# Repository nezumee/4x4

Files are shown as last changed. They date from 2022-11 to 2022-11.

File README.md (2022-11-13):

# 4x4 keyboard
 
The 4x4 keyboard is a modular keyboard with per-key RGB lighting intended to be used as a base for prototyping MIDI controller with QMK firmware.

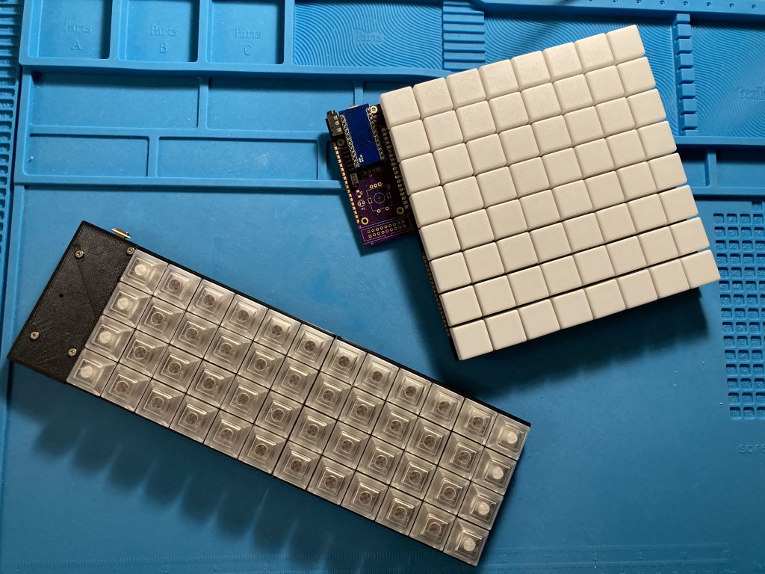
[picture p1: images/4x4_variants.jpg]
4x4 variants


It consists of the following parts:
* Head PCB with MCU and other connectors
* 1 to 4 key PCB, each having 16 hotswap Cherry MX switches in 4x4 layout

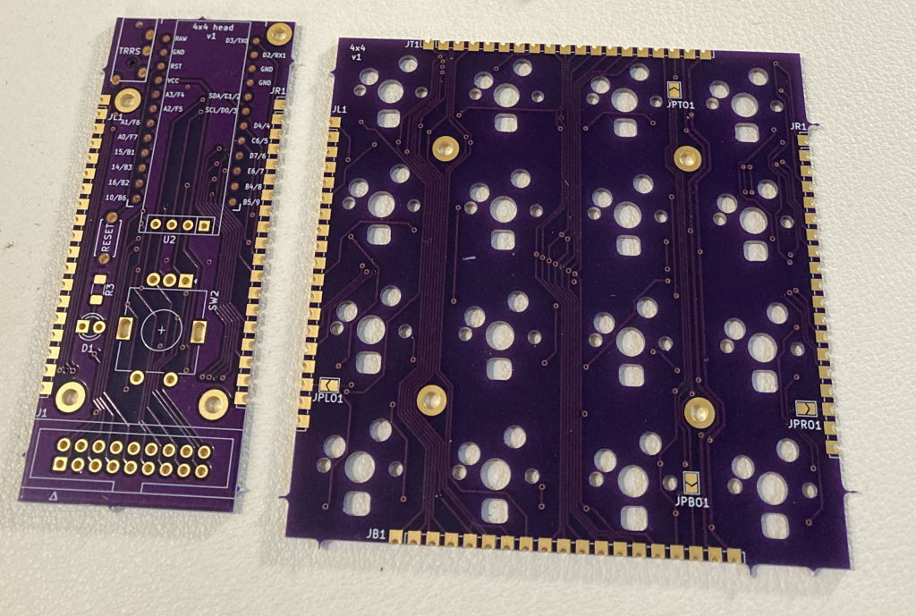
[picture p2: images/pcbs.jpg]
PCB parts


These parts can be soldered together in different configurations, resulting in different layouts, such as 4x12 Planck layout or 8x8 layout similar to MIDI drumpads controllers.

The modular design allows to iterate on parts of it without remaking a large PCB. It also makes it cost-effective to order from PCB prototyping service - ordering the typical minimum of 3 to 5 pieces of key PCB makes a single full-sized keyboard with no excessive number of spares.

PCB pieces use castellated pads to route all the signals. These pads are soldered together placing the PCBs side by side, connecting them electrically and also holding them together physically.

## Switch matrix

To allow for modularity and avoid using lots of wires to connect parts together, electrical layout of the key PCBs doesn't match their physical layout. Even though physically they are 4x4, electrically switches are laid out in 2 columns and 8 rows:
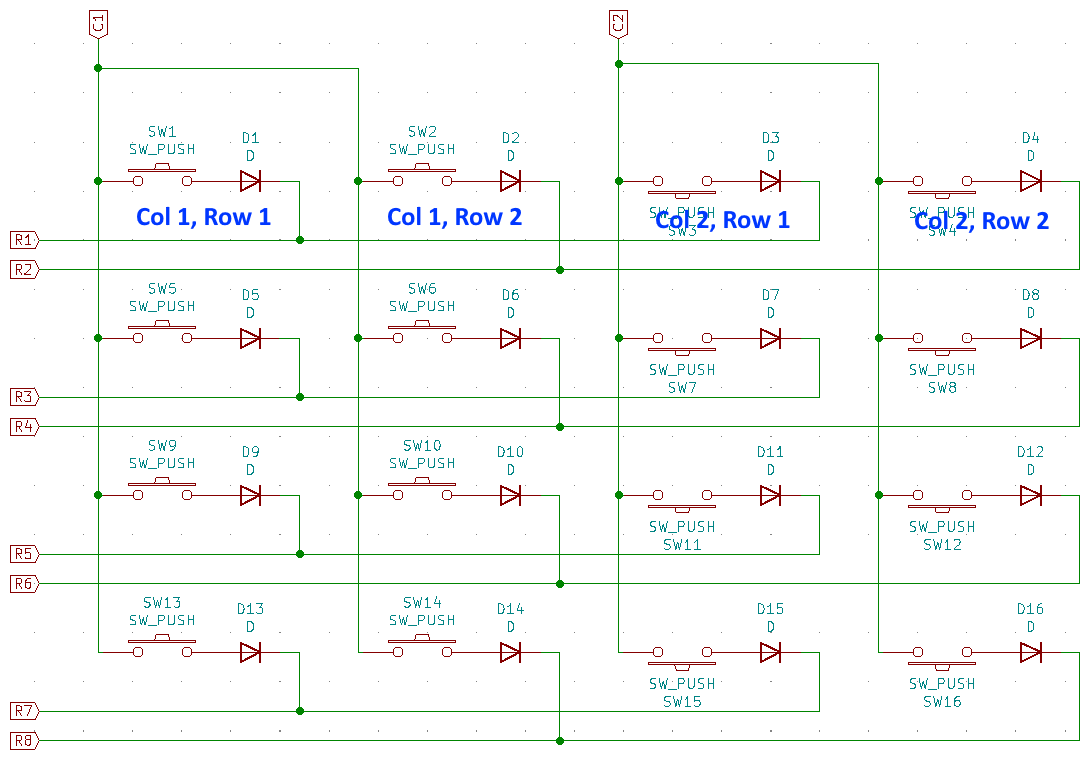
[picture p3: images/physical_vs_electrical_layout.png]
physical vs electrical layout
 Each key module uses the same row wires but separate columns so the full electrical layout is 8x8 if there are 4 key modules.

The column lines are routed through the key PCBs such that columns are shifted in the next connected module: if a key module is directly connected to the head, it will connect to columns 1 and 2. Module attached to the right of it will use columns 3 and 4, and so on. Attaching a module to the bottom of another shifts columns by 4 instead. The end result is that in all supported configurations, simply soldering the key modules together in the desired layout gives each of them a unique pair of column wires connected to the MCU.

Row lines are not shifted, they are passed through across the key modules as is and connect to the same MCU pin in every module.

## LED connections

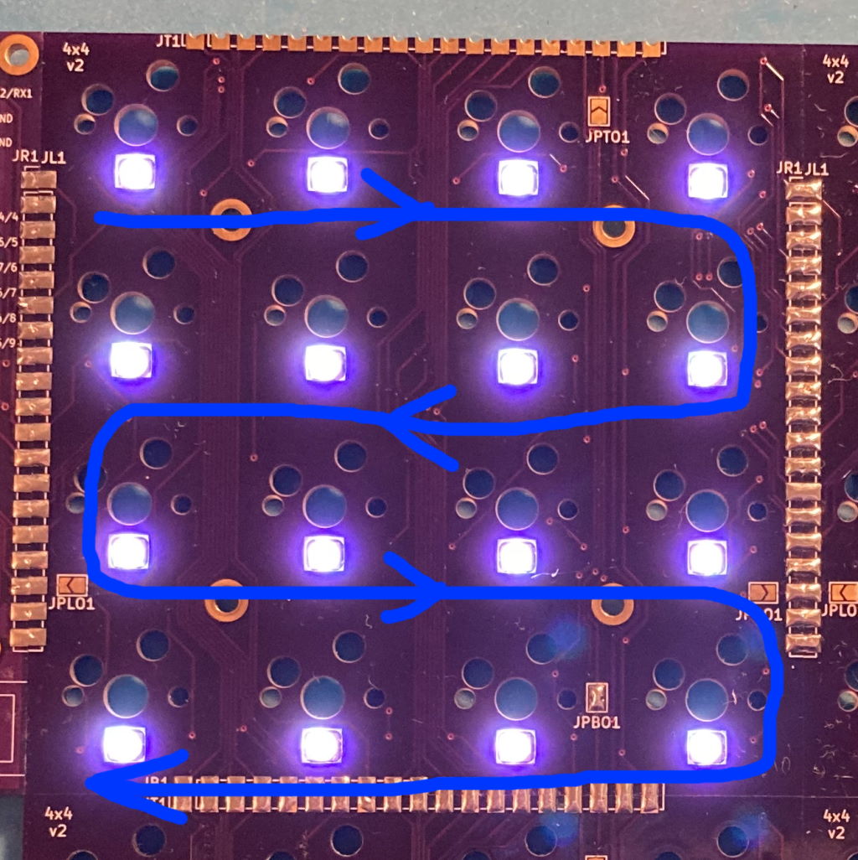
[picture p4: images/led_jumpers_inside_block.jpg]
LED order inside block
WS6812 mini-e LEDs are used to provide per-key RGB. These LEDs require that they are connected in a chain to let the signal propagate from one LED to another. Within each key module, they are connected like this: 

To connect them across key modules, jumpers need to be soldered on each module to specify the side that takes LED input from previous module in the chain, and the side connecting to the next module:
* JP(L/R/T/B)I jumpers specify the left/right/top/bottom side as input
* JP(L/R/T/B)O jumpers specify the output side

This builds a chain of key modules, connecting the last LED in the preceding module to the first LED in the next:

* Input jumpers:
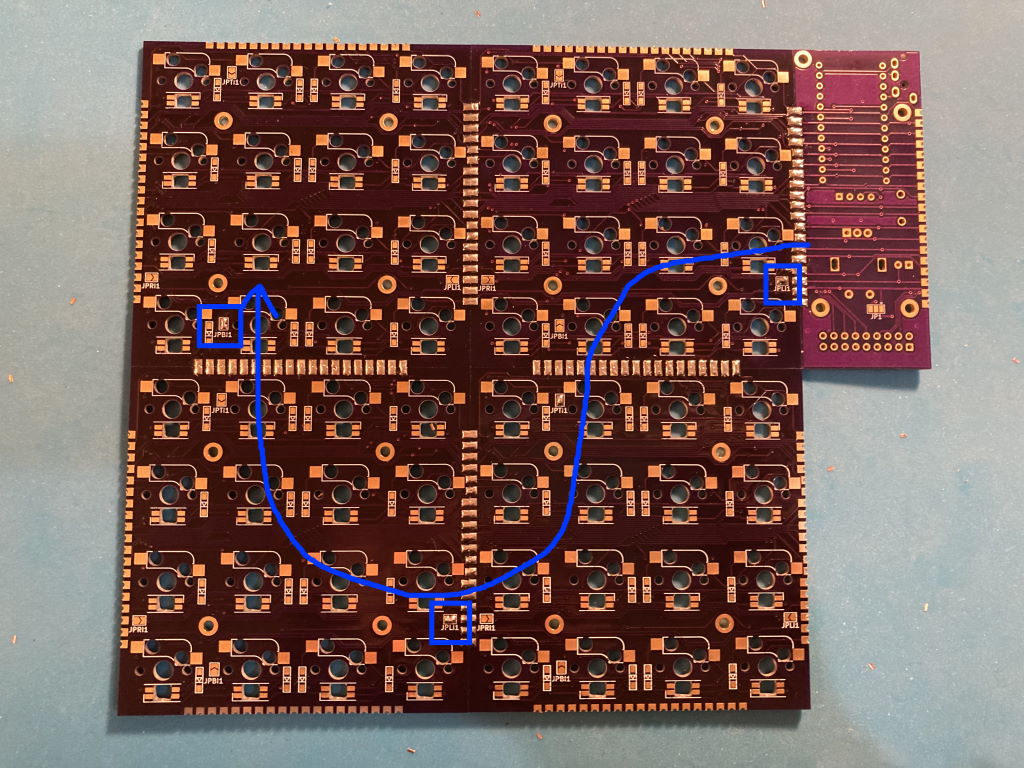
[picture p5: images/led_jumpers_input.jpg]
input jumpers

* Output jumpers:
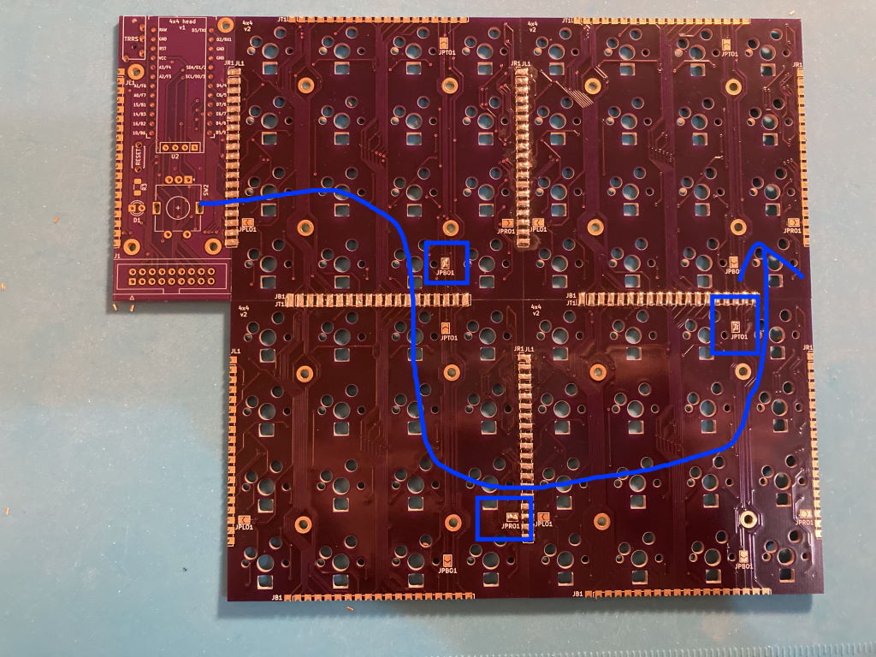
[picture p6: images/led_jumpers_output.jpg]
input jumpers


## Bill of material

| Item | Quantity | Comment | Source |
| --- | --- | --- | --- |
| Head PCB | 1 | [KiCad source](pcb/headfour/) | [gerber](pcb/gerbers/headfour.zip) |
| Key PCBs | 1-4 | [KiCad source](pcb/fourbyfour/) | [gerber](pcb/gerbers/fourbyfour.zip) |
| ProMicro MCU | 1 |
| MCU socket | 1 | 2 strips of 12 pins each | https://www.digikey.com/en/products/detail/mill-max-manufacturing-corp/310-43-112-41-001000/1212186 |
| Reset tactile button | 1 | |
| TRRS jack | 1 | To support split keyboard, optional | https://boardsource.xyz/store/5eca3b7d64caf04f83aa6488 |
| Kailh MX hotswap sockets | 16-64 | | https://boardsource.xyz/store/5eca066464caf04f83aa647f |
| N4148 SOD-123 diodes | 16-64 | | https://www.digikey.com/en/products/detail/panjit-international-inc/1N4148W-R1-00001/14660400 |
| SK6812 mini-e RGB LEDs | 16-64 | Optional | https://boardsource.xyz/store/5f6316e0a2c1b43e37ca04c3 |
| Cherry MX compatible switches, keycaps | 16-64 |
| Switch plate, case | | Optional | See some example designs [here](case/)
| M2 bolts and standoffs | 8-20 |

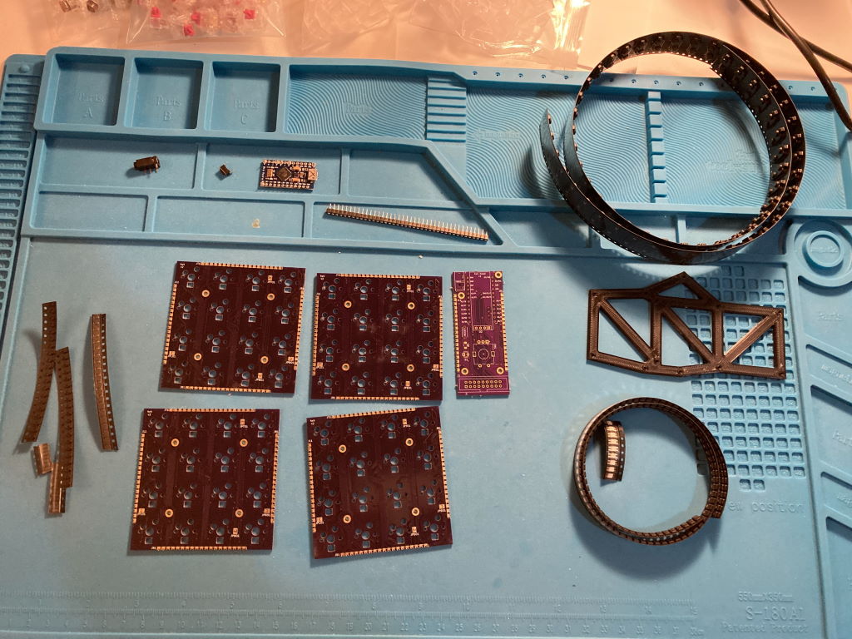
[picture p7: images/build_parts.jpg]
parts before build


## Build

1. Decide on the layout
    * Options: horizontal strip of 1-4, vertical strip of 2, 2x2 square  
    * Head position: any side of the key block, facing up or left    
2. Prep the PCBs
	1. Clean up the castellated edges if needed. Make sure key PCBs sit flush to each other
	2. Make sure LEDs fit in the holes, file to enlarge them if necessary
3. Solder together the PCBs pieces
	1. Use something to help hold PCBs together, like [the 3d printed holder](misc/4x4holder.stl)
        * Make sure both PCBs face the same way before soldering
        * Make sure PCBs sit flat and even as you solder, using a ruler to check they don't bend at the seam once every few soldered pads:
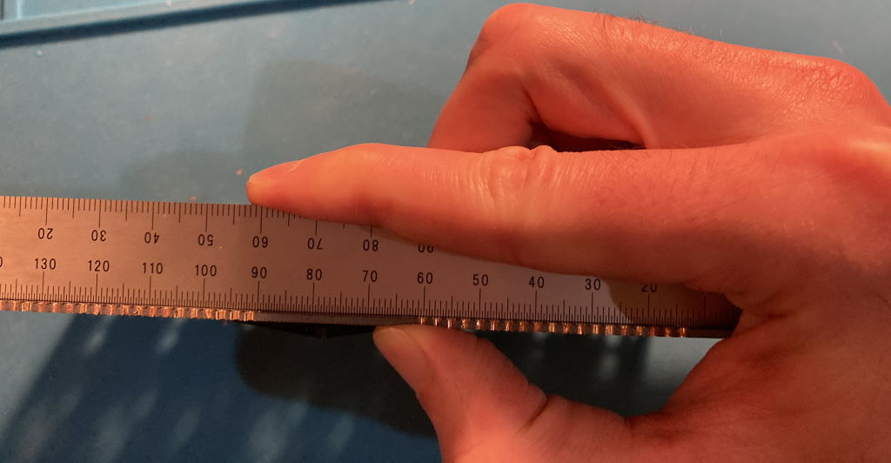
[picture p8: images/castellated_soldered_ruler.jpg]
are PCBs flat?
        
        * Tip: if using a 3D printed frame to hold PCBs, add washers before screwing the PCBs to it so plastic doesn't touch the hot contacts as you solder them
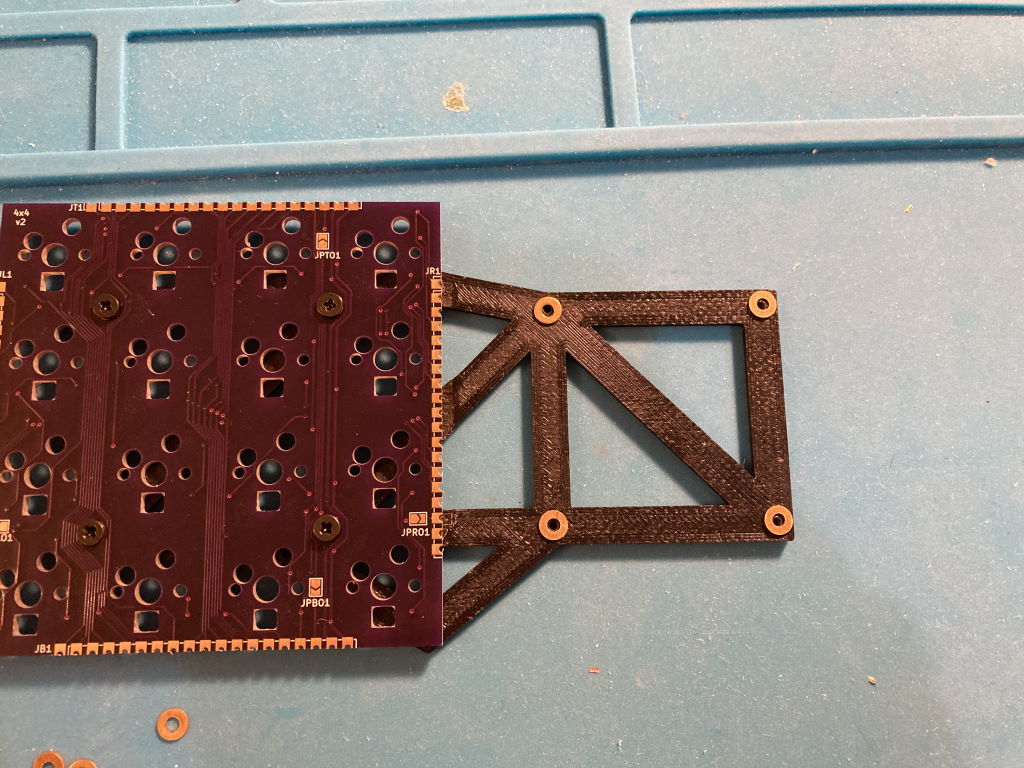
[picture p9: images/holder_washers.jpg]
holder with washers
        	
	2. Turn over and clean up on the other side
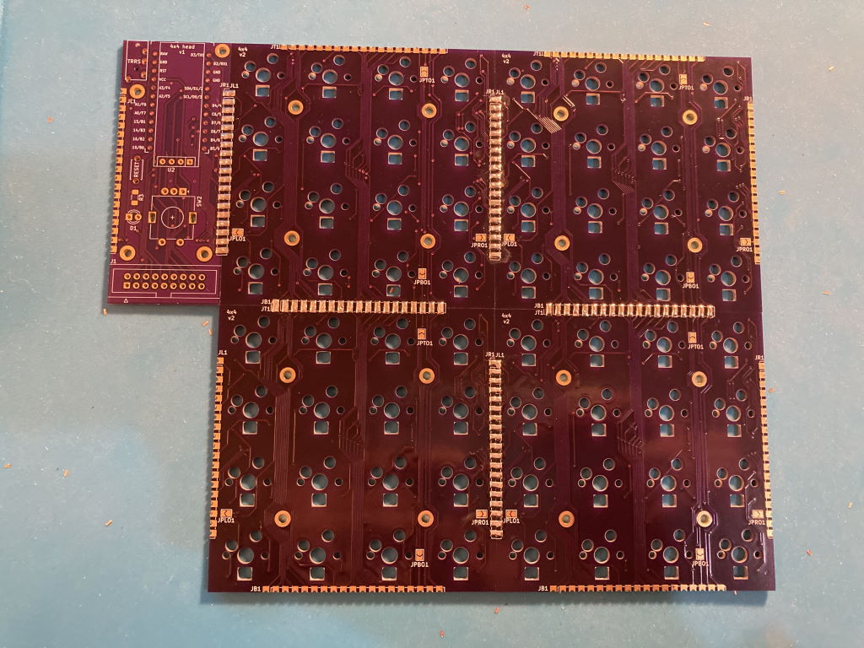
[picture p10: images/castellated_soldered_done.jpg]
all soldered together
    
	
4. Solder the jumpers for LED signal chaining
5. Solder the MCU socket so that you can test the rest as you go
6. Solder the per-key elements
    1. LEDs
	2. Diodes
	3. Switch hotswap sockets
7. Solder the remaining head elements
	1. TRRS jack
	2. Reset tactile button

End result:
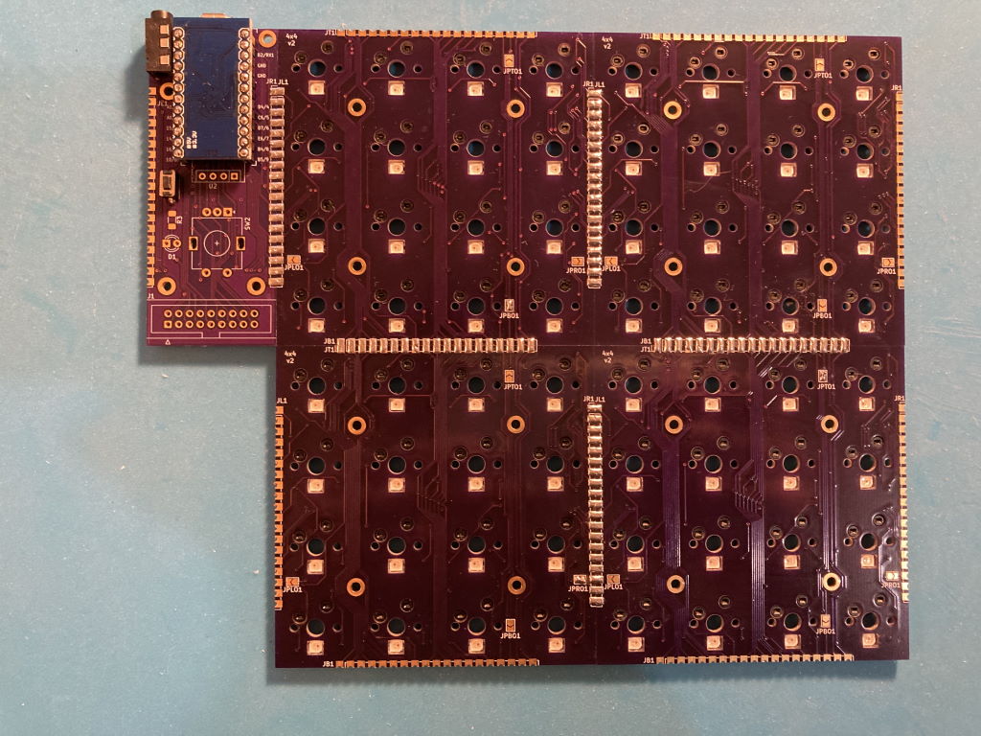
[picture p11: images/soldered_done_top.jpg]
top
* Top 
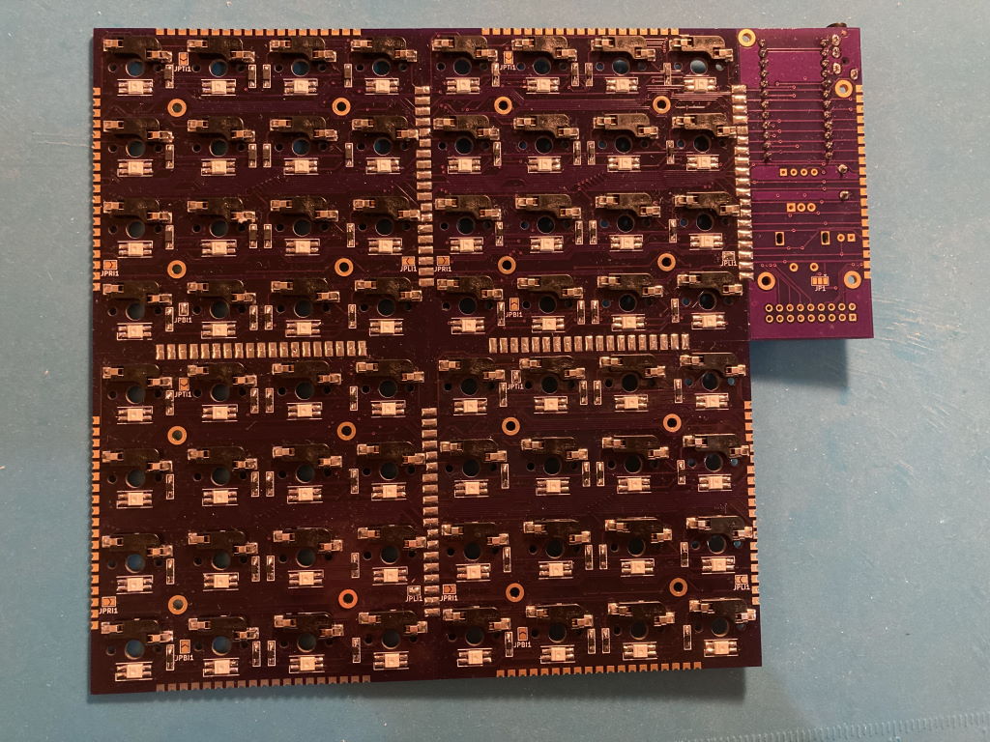
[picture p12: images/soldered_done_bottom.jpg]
bottom
* Bottom 

## Firmware

This keyboard is using [QMK](https://qmk.fm/). Example layout making the keyboard work as a combination of planck keyboard and a MIDI controller is available [here](https://github.com/nezumee/qmk_firmware/tree/4x4/keyboards/4x4/keymaps/midi-controller). Note that you need [the MIDI input fix](https://github.com/qmk/qmk_firmware/pull/18654) for the MIDI feedback to work.

## Using 4x4 as a MIDI controller

QMK has MIDI support that allows using the keyboard as a MIDI controller. Per-key RGB also makes it possible to have MIDI feedback, such that each key lights up depending on the status in the DAW. For example, you can set it up that keyboard keys trigger clips or scenes, and have those keys light up in the right color when there's an active clip or when a track is armed for recording.

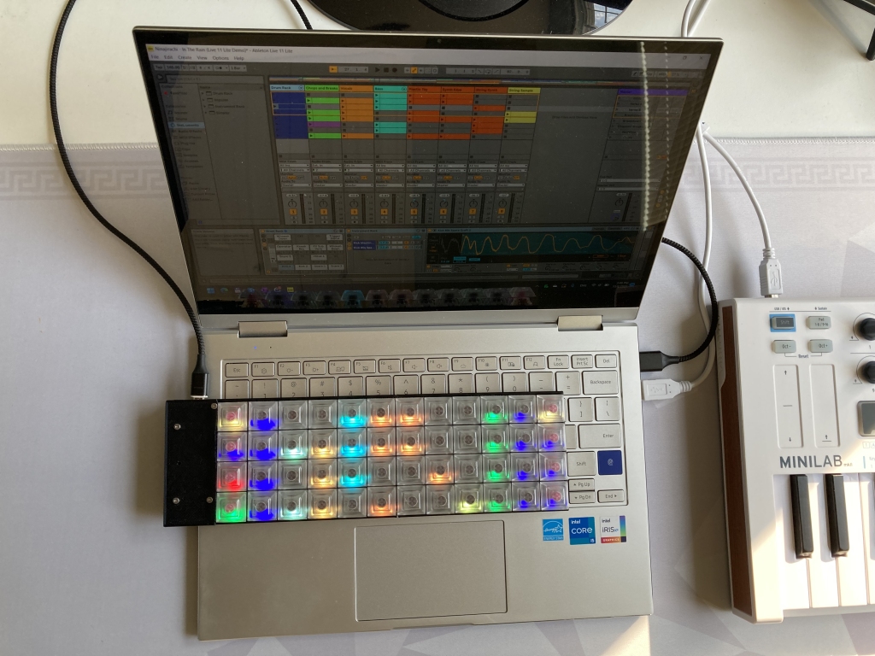
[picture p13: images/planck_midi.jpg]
planck layout with MIDI clips


This support requires some integration in the DAW. Remote MIDI script for Ableton Live working with the Planck-like layout is [here](ableton_live/FourByFour).

## Known problems

* Head v1
	* There are OLED and encoder footprints, but they cannot be used since the same pins are reused for switch rows
* Brightness must be restricted when using many LEDs (48+), voltage regulator in ProMicro cannot handle them otherwise
* Split keyboard is not tested, is challenging due to LED power consumption

## License

This project is using the [MIT license](LICENSE).

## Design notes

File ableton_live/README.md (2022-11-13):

These scripts have been created based on https://github.com/laidlaw42/ableton-live-midi-remote-scripts , with some tweaks added.
---

# Ableton Live Custom MIDI Remote Scripts

Scripts for creating custom MIDI Remote Scripts for Ableton Live.
Known to be working on Live 9 and 10, untested in 11.

---
### Background
This is an [in-depth tutorial](https://youtu.be/IgKwcCJsoz4) on how to use these scripts. 
When I made the video 5 years ago, I had next to no programming knowledge, and I created it with the intent 
that non-programmers would be able to make their own MIDI scripts to interface with Live. 30k views later... it probably
deserves an update. The video has more details about what to modify to get things working, but I'll add more comments
to the code as I figure out what each function does.

- Most of the code is from these [Behringer FCB1020 scripts](http://remotescripts.blogspot.com) by Hanz Petrov, if I 
  can find their git or another source to credit them appropriately then I will do so. Let me know here if the site is gone, I have archived it for
  posterity.
- For the Push 2, user [jzgdev](https://github.com/jzgdev/Push2UserModeScript) has a working Push 2 User Mode.
- [More information](https://structure-void.com/ableton-live-midi-remote-scripts/) on MIDI remote scripts, the Live API 
  documentation, Push scripts, and [decompiled scripts](https://github.com/gluon) for more current versions of Live by 
  Julien Bayle.

---
### Instructions

- Connect your MIDI device to your computer
- Open Live and navigate to `Preferences → Link MIDI → MIDI`
- Under either the Input or Output press the dropdown menu, note the exact name of your controller (if spaces are present in name, use underscores (e.g. "Arturia_Beatstep" 
  instead of "Arturia Beatstep").
- Close Live.
- Find and replace all instances in the scripts of `YourControllerName` folder with your controller's name.
  - There are three in `__init__.py`
  - and nine in `YourControllerName.py`
- Save everything
- Rename the YourControllerName folder and the `YourControllerName.py` with the same name.
- Open `MIDI_Map.py` and inspect what you want to control. Unless stated otherwise, `-1` is the idle/unused value for 
  each parameter. 
- You can use a third-party tool (see: [Downloads](#downloads)), or your device's user manual to figure out what MIDI
  channel, note or CC values each control on your device sends.
  I'd do this with pen and paper or [draw.io](https://draw.io).
- Once you know your layout, assign the values to the respective parameter in `MIDI_Map.py` and ensure you set 
`BUTTONCHANNEL` and `SLIDERCHANNEL` to the same MIDI channel as your buttons and pots/faders. 
- <b>Important</b>: you must use the value for decimal number when assigning MIDI notes/buttons, <u><b>DO NOT</u></b> 
  use note values like these C3, D4, A1 etc., they won't work. There are tables to work it out from the note, but the
  software is much more efficient and accurate.
- Save and close everything and make a backup of your edited version, Live 9 compiles your scripts on launch, so you
  won't be able to make edits after it has done that. You've been warned. Don't let that effort be for nothing.

MIDI Remote Scripts folder:
  - For Windows users: `\ProgramData\Ableton\Live x.x\Resources\MIDI Remote Scripts\`
  - For macOS users:
    - Locate the Live application in Finder (typically `/Applications/`), 
    - right click on it and select "Show Package Contents" in the context menu,
    - navigate to: `/Contents/App-Resources/MIDI Remote Scripts/`
- If you have multiple versions of Live installed, you will have to copy your scripts to each version individually.
- If you are replacing a pre-existing script with the same device name then make a copy of the original. 
  Otherwise, you will have to reinstall Live to get the default scripts back.
- Launch Live and head back to `Preferences → Link MIDI → MIDI`
- Under the `Control Surface` section, choose an empty slot and assign your newly created script.
- Set the Input and Output to your MIDI device.
- Under `MIDI Ports` check that `Remote` and `Track' are set to `On` for both the Input and the Output, or to 
your preference if you know what you're doing.
- Test it out.
- There is going to be a lot of trial and error here but it's pretty straightforward once you get an input working.   

---
### Troubleshooting:
- Make sure `YourControllerName` is changed everywhere, and you saved the script before placing it in the 
  `MIDI Remote Scripts` directory.
- Set the `BUTTONCHANNEL` and the `SLIDERCHANNEL` correctly. It won't work until you do that.
- If you have multiple versions of Live installed, you will have to copy your scripts to each version individually.
- Assign one control message (CC/Note) per parameter.
- Before you add to `MIDI Remote Scripts` folder just make sure you have the correct MIDI channels and renamed 
  YourControllerName in `__init__.py` and `YourControllerName.py`. Don't forget to change the folder and the file names
  as well.

---
### Updates
- Change the size of the track selection box (coloured box in Session view).
  - There are now two variables in MIDI_Map.py to modify the size of the box:
    - `TSB_X` is the horizontal count i.e. the number of tracks
    - `TSB_Y` is the vertical count which represents the number of scenes you want to control.
  - For this to work properly you must manually add or remove rows/columns for `SCENELAUNCH` and `CLIPNOTEMAP` 
  sections in [MIDI_Map.py](https://github.com/laidlaw42/Ableton-Live-MIDI-Remote-Scripts/blob/YourControllerName/YourControllerName/MIDI_Map.py).

---
### Downloads
- [MIDI Manager](https://www.snoize.com/midimonitor/) for macOS (preferred).
- [MIDI Tools](https://mountainutilities.eu/miditools) for Windows and macOS.
- [BCRManager](http://mountainutilities.eu/bcmanager) a GUI software solution for editing the Behringer BCR2000. 
- [Atom](https://atom.io) the code editor I mention in the video.
- [PyCharm](https://www.jetbrains.com/pycharm/) probably a better editor to use if you're going to get into Python.

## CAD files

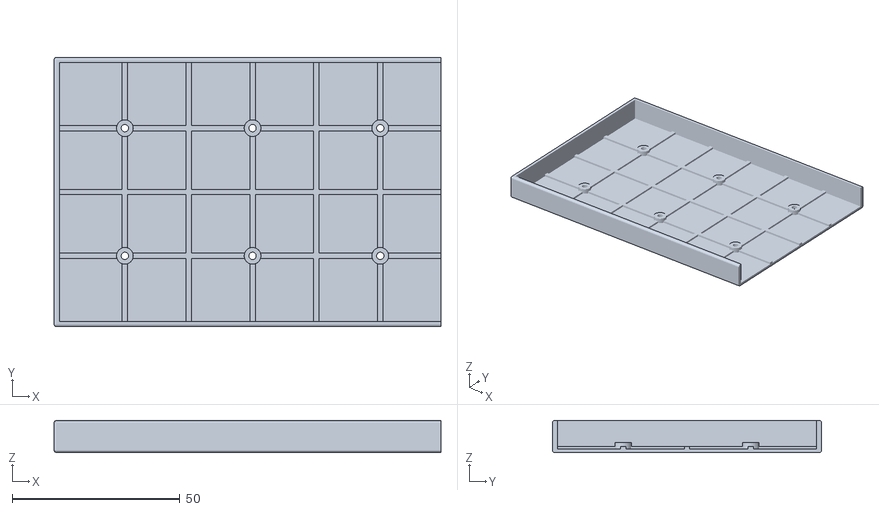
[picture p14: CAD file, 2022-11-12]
case/planck_case_half.stl
115.5 x 80.4 x 9.60

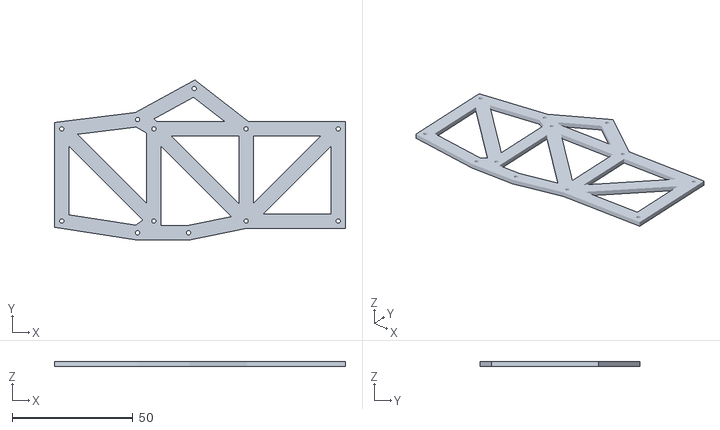
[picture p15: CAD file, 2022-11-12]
misc/4x4holder.stl
120.3 x 66.2 x 2.00

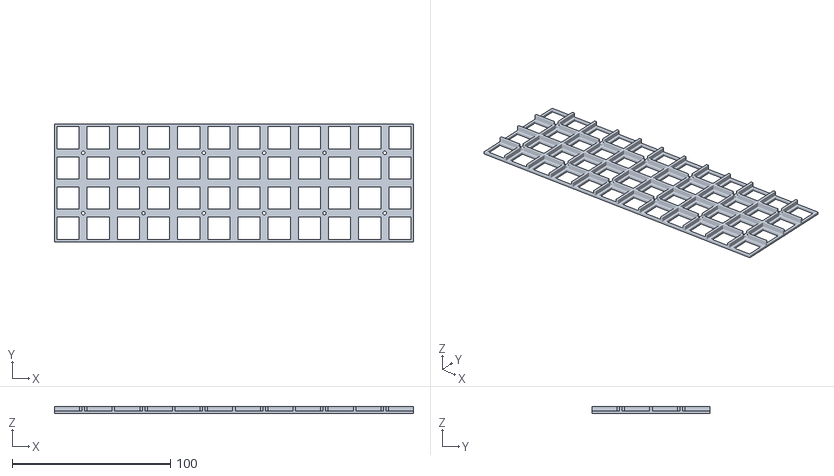
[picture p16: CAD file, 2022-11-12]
case/planck_plate.stl
226.7 x 74.4 x 4.70

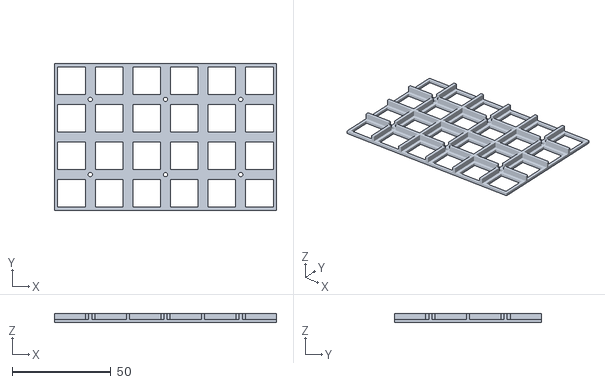
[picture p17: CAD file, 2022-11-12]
case/planck_plate_half.stl
112.4 x 74.4 x 4.70

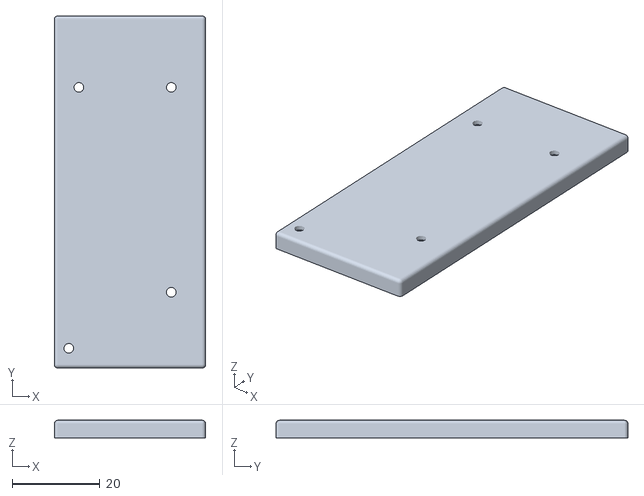
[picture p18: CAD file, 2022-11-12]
case/planck_mcu_shield.stl
34.6 x 80.4 x 4.00

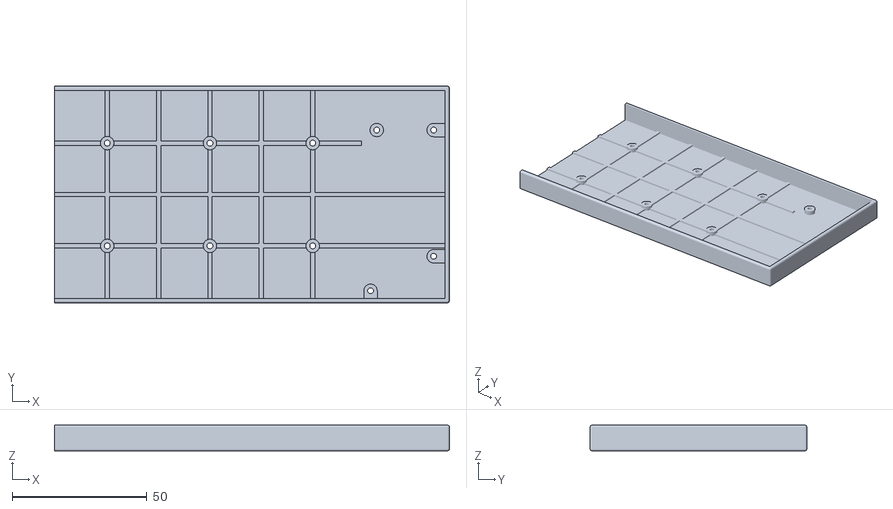
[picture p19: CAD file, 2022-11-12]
case/planck_case_left.stl
146.5 x 80.4 x 9.60

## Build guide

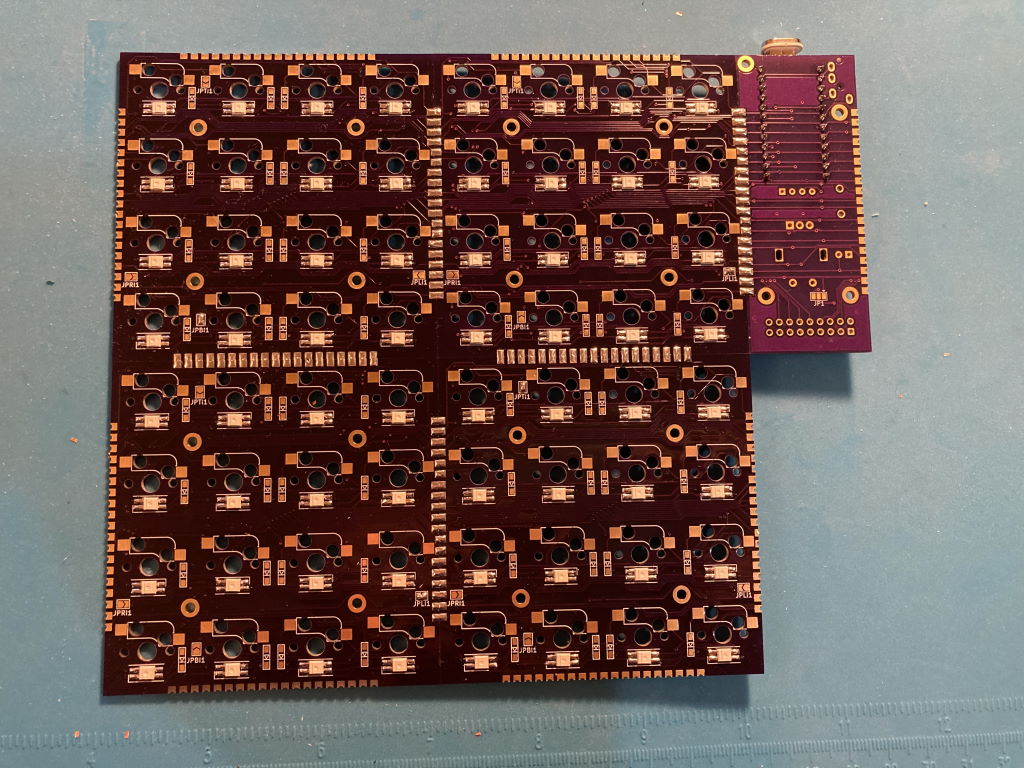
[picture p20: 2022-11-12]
images/soldered_leds.jpg

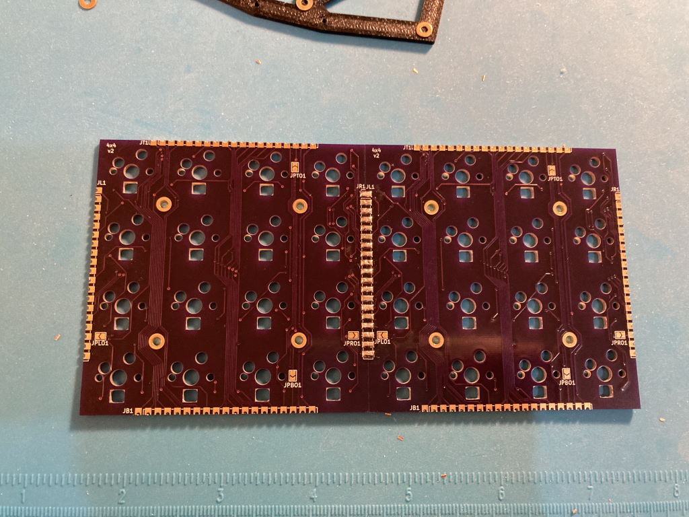
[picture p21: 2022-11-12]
images/castellated_soldered_1.jpg

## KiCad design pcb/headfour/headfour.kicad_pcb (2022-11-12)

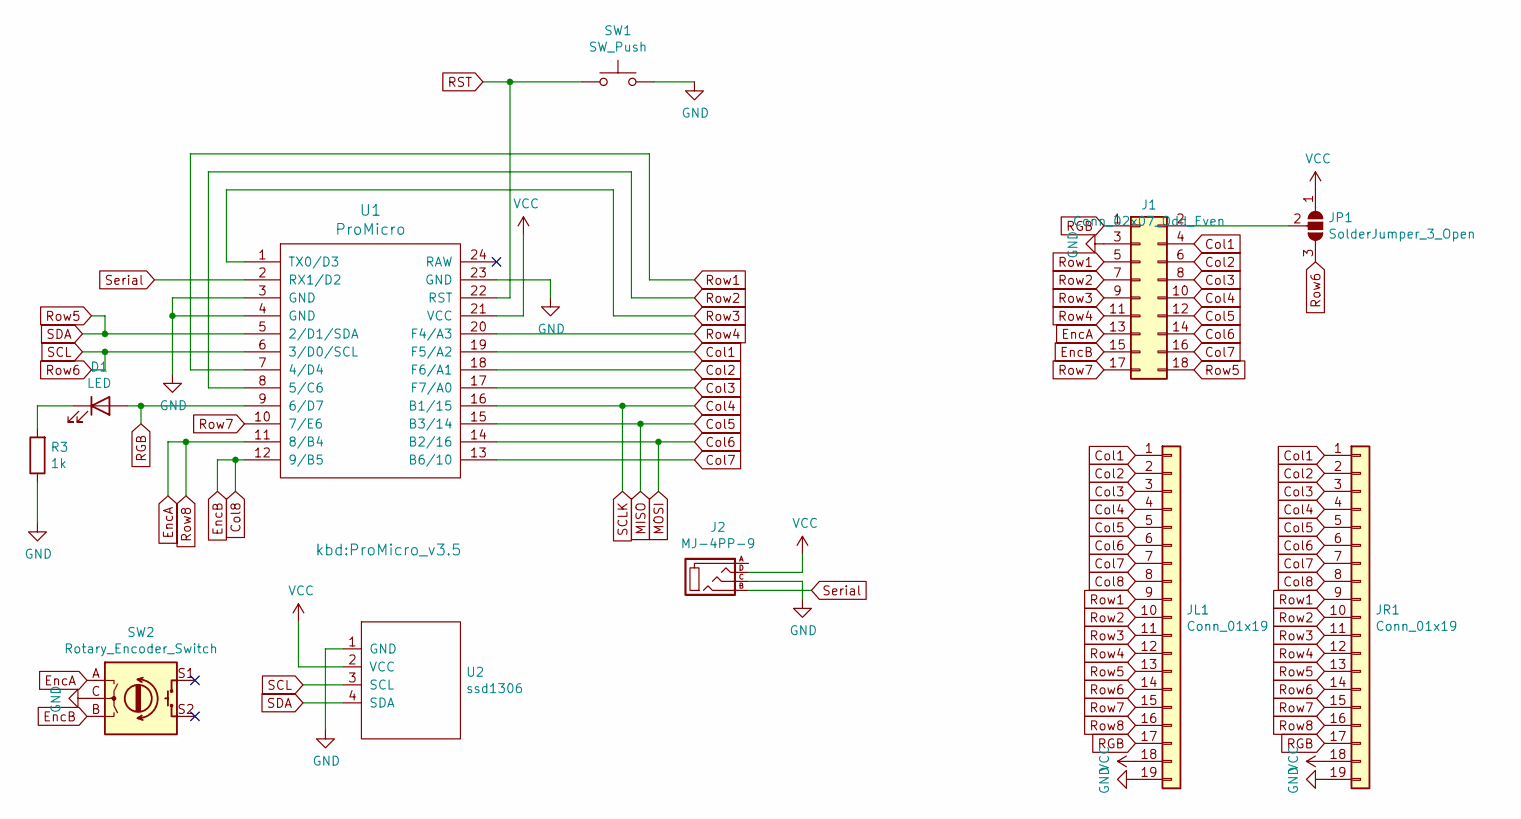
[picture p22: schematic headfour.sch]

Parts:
D1: LED; LED_D3.0mm
J1: Conn_02x07_Odd_Even; IDC-Header_2x09_P2.54mm_Vertical
J2: MJ-4PP-9; MJ-4PP-9_1side
JL1: Conn_01x19; PinHeader_1x19_P2.54mm_CastellatedR
JP1: SolderJumper_3_Open; SolderJumper-3_P1.3mm_Open_Pad1.0x1.5mm
JR1: Conn_01x19; PinHeader_1x19_P2.54mm_CastellatedL
R3: 1k; R_1206_3216Metric_Pad1.30x1.75mm_HandSolder
SW1: SW_Push; ResetSW_1side
SW2: Rotary_Encoder_Switch; RotaryEncoder_Alps_EC11E-Switch_Vertical_H20mm
U1: ProMicro; ProMicro_v3.5
U2: ssd1306; SSD1306

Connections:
Col1: J1.4, JL1.1, JR1.1, U1.19 (F5/A2)
Col2: J1.6, JL1.2, JR1.2, U1.18 (F6/A1)
Col3: J1.8, JL1.3, JR1.3, U1.17 (F7/A0)
Col4: J1.10, JL1.4, JR1.4, U1.16 (B1/15)
Col5: J1.12, JL1.5, JR1.5, U1.15 (B3/14)
Col6: J1.14, JL1.6, JR1.6, U1.14 (B2/16)
Col7: J1.16, JL1.7, JR1.7, U1.13 (B6/10)
Col8: J1.15, JL1.8, JR1.8, SW2.B, U1.12 (9/B5)
EncA: J1.13, JL1.16, JR1.16, SW2.A, U1.11 (8/B4)
GND: J1.3, J2.C, JL1.19, JR1.19, R3.1, SW1.2, SW2.C, U1.3 (GND), U1.4 (GND), U1.23 (GND), U2.1 (GND)
unnamed: D1.1 (K), R3.2
unnamed: J1.2, JP1.2 (C)
RGB: D1.2 (A), J1.1, JL1.17, JR1.17, U1.9 (6/D7)
RST: SW1.1, U1.22 (RST)
Row1: J1.5, JL1.9, JR1.9, U1.7 (4/D4)
Row2: J1.7, JL1.10, JR1.10, U1.8 (5/C6)
Row3: J1.9, JL1.11, JR1.11, U1.1 (TX0/D3)
Row4: J1.11, JL1.12, JR1.12, U1.20 (F4/A3)
Row5: J1.18, JL1.13, JR1.13, U1.5 (2/D1/SDA), U2.4 (SDA)
Row6: JL1.14, JP1.3 (B), JR1.14, U1.6 (3/D0/SCL), U2.3 (SCL)
Row7: J1.17, JL1.15, JR1.15, U1.10 (7/E6)
Serial: J2.B, U1.2 (RX1/D2)
VCC: J2.D, JL1.18, JP1.1 (A), JR1.18, U1.21 (VCC), U2.2 (VCC)

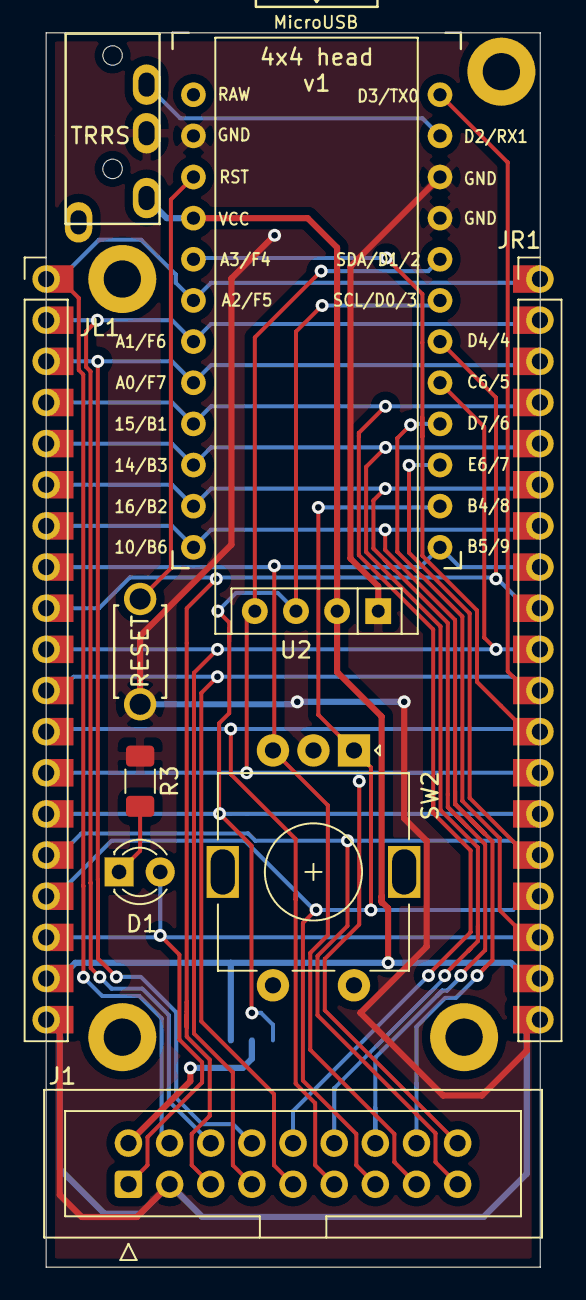
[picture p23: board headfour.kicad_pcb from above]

Board: 2 copper layers, 30.5 x 76.2 mm, 11 parts (1 on the bottom side), 23 nets.

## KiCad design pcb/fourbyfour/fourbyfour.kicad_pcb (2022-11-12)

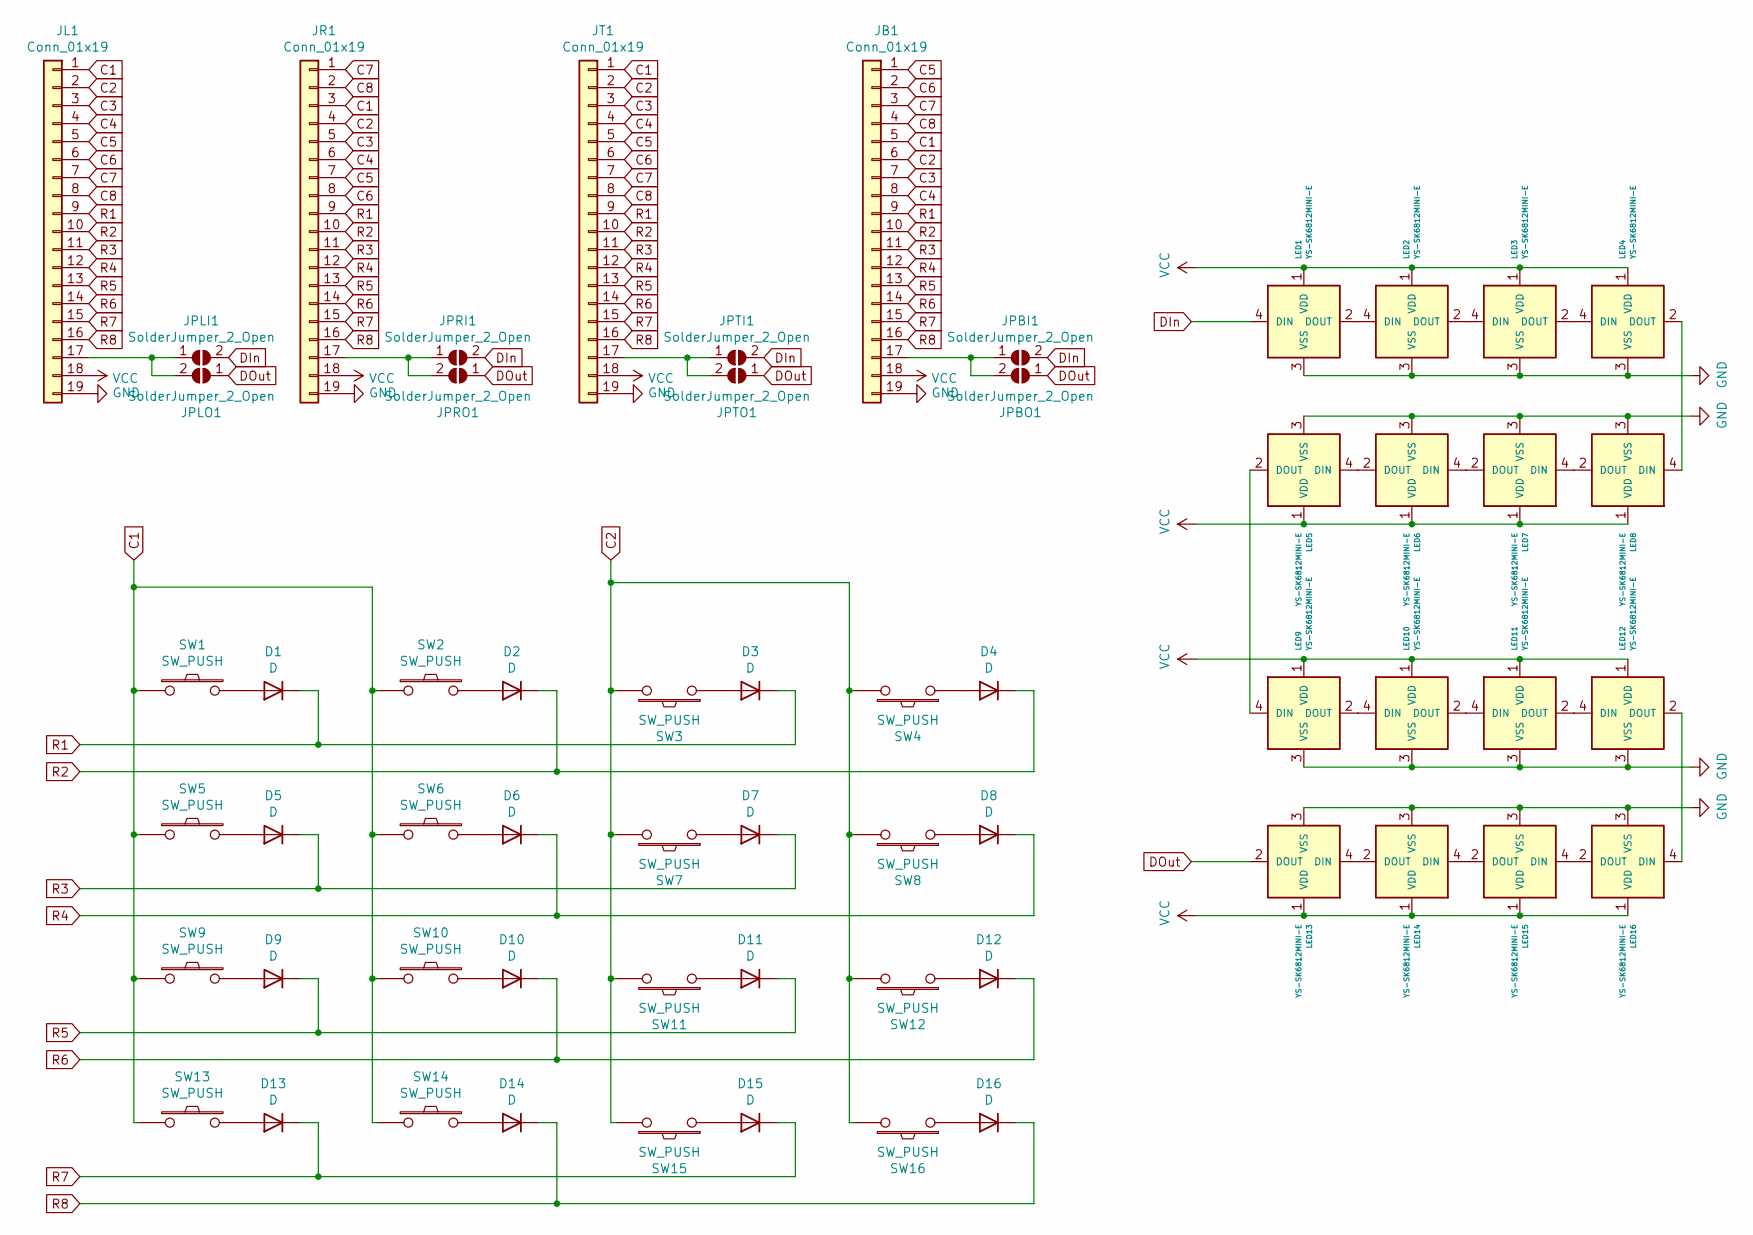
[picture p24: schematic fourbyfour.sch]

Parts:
D1, D2, D3, D4, D5, D6, D7, D8, D9, D10, D11, D12, D13, D14, D15, D16: D; D3_SMD_v2
JB1: Conn_01x19; PinHeader_1x19_P2.54mm_CastellatedR
JL1: Conn_01x19; PinHeader_1x19_P2.54mm_CastellatedR
JPBI1: SolderJumper_2_Open; SolderJumper-2_P1.3mm_Open_TrianglePad1.0x1.5mm
JPBO1: SolderJumper_2_Open; SolderJumper-2_P1.3mm_Open_TrianglePad1.0x1.5mm
JPLI1: SolderJumper_2_Open; SolderJumper-2_P1.3mm_Open_TrianglePad1.0x1.5mm
JPLO1: SolderJumper_2_Open; SolderJumper-2_P1.3mm_Open_TrianglePad1.0x1.5mm
JPRI1: SolderJumper_2_Open; SolderJumper-2_P1.3mm_Open_TrianglePad1.0x1.5mm
JPRO1: SolderJumper_2_Open; SolderJumper-2_P1.3mm_Open_TrianglePad1.0x1.5mm
JPTI1: SolderJumper_2_Open; SolderJumper-2_P1.3mm_Open_TrianglePad1.0x1.5mm
JPTO1: SolderJumper_2_Open; SolderJumper-2_P1.3mm_Open_TrianglePad1.0x1.5mm
JR1: Conn_01x19; PinHeader_1x19_P2.54mm_CastellatedL
JT1: Conn_01x19; PinHeader_1x19_P2.54mm_CastellatedL
LED1, LED2, LED3, LED4, LED5, LED6, LED7, LED8, LED9, LED10, LED11, LED12, LED13, LED14, LED15, LED16: YS-SK6812MINI-E
SW1, SW2, SW3, SW4, SW5, SW6, SW7, SW8, SW9, SW10, SW11, SW12, SW13, SW14, SW15, SW16: SW_PUSH; CherryMX_Hotswap

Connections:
C1: JB1.5, JL1.1, JR1.3, JT1.1, SW1.1, SW2.1, SW5.1, SW6.1, SW9.1, SW10.1, SW13.1, SW14.1
C2: JB1.6, JL1.2, JR1.4, JT1.2, SW3.2, SW4.2, SW7.2, SW8.2, SW11.2, SW12.2, SW15.2, SW16.2
C3: JB1.7, JL1.3, JR1.5, JT1.3
C4: JB1.8, JL1.4, JR1.6, JT1.4
C5: JB1.1, JL1.5, JR1.7, JT1.5
C6: JB1.2, JL1.6, JR1.8, JT1.6
C7: JB1.3, JL1.7, JR1.1, JT1.7
C8: JB1.4, JL1.8, JR1.2, JT1.8
DIn: JPBI1.2 (B), JPLI1.2 (B), JPRI1.2 (B), JPTI1.2 (B), LED1.4 (DIN)
DOut: JPBO1.1 (A), JPLO1.1 (A), JPRO1.1 (A), JPTO1.1 (A), LED13.2 (DOUT)
GND: JB1.19, JL1.19, JR1.19, JT1.19, LED1.3 (VSS), LED2.3 (VSS), LED3.3 (VSS), LED4.3 (VSS), LED5.3 (VSS), LED6.3 (VSS), LED7.3 (VSS), LED8.3 (VSS), LED9.3 (VSS), LED10.3 (VSS), LED11.3 (VSS), LED12.3 (VSS), LED13.3 (VSS), LED14.3 (VSS), LED15.3 (VSS), LED16.3 (VSS)
unnamed: D1.2 (A), SW1.2
unnamed: D2.2 (A), SW2.2
unnamed: D3.2 (A), SW3.1
unnamed: D4.2 (A), SW4.1
unnamed: D5.2 (A), SW5.2
unnamed: D6.2 (A), SW6.2
unnamed: D7.2 (A), SW7.1
unnamed: D8.2 (A), SW8.1
unnamed: D9.2 (A), SW9.2
unnamed: D10.2 (A), SW10.2
unnamed: D11.2 (A), SW11.1
unnamed: D12.2 (A), SW12.1
unnamed: D13.2 (A), SW13.2
unnamed: D14.2 (A), SW14.2
unnamed: D15.2 (A), SW15.1
unnamed: D16.2 (A), SW16.1
unnamed: JB1.17, JPBI1.1 (A), JPBO1.2 (B)
unnamed: JL1.17, JPLI1.1 (A), JPLO1.2 (B)
unnamed: JPRI1.1 (A), JPRO1.2 (B), JR1.17
unnamed: JPTI1.1 (A), JPTO1.2 (B), JT1.17
unnamed: LED1.2 (DOUT), LED2.4 (DIN)
unnamed: LED2.2 (DOUT), LED3.4 (DIN)
unnamed: LED3.2 (DOUT), LED4.4 (DIN)
unnamed: LED4.2 (DOUT), LED8.4 (DIN)
unnamed: LED5.2 (DOUT), LED9.4 (DIN)
unnamed: LED5.4 (DIN), LED6.2 (DOUT)
unnamed: LED6.4 (DIN), LED7.2 (DOUT)
unnamed: LED7.4 (DIN), LED8.2 (DOUT)
unnamed: LED10.2 (DOUT), LED11.4 (DIN)
unnamed: LED9.2 (DOUT), LED10.4 (DIN)
unnamed: LED11.2 (DOUT), LED12.4 (DIN)
unnamed: LED12.2 (DOUT), LED16.4 (DIN)
unnamed: LED13.4 (DIN), LED14.2 (DOUT)
unnamed: LED14.4 (DIN), LED15.2 (DOUT)
unnamed: LED15.4 (DIN), LED16.2 (DOUT)
R1: D1.1 (K), D3.1 (K), JB1.9, JL1.9, JR1.9, JT1.9
R2: D2.1 (K), D4.1 (K), JB1.10, JL1.10, JR1.10, JT1.10
R3: D5.1 (K), D7.1 (K), JB1.11, JL1.11, JR1.11, JT1.11
R4: D6.1 (K), D8.1 (K), JB1.12, JL1.12, JR1.12, JT1.12
R5: D9.1 (K), D11.1 (K), JB1.13, JL1.13, JR1.13, JT1.13
R6: D10.1 (K), D12.1 (K), JB1.14, JL1.14, JR1.14, JT1.14
R7: D13.1 (K), D15.1 (K), JB1.15, JL1.15, JR1.15, JT1.15
R8: D14.1 (K), D16.1 (K), JB1.16, JL1.16, JR1.16, JT1.16
VCC: JB1.18, JL1.18, JR1.18, JT1.18, LED1.1 (VDD), LED2.1 (VDD), LED3.1 (VDD), LED4.1 (VDD), LED5.1 (VDD), LED6.1 (VDD), LED7.1 (VDD), LED8.1 (VDD), LED9.1 (VDD), LED10.1 (VDD), LED11.1 (VDD), LED12.1 (VDD), LED13.1 (VDD), LED14.1 (VDD), LED15.1 (VDD), LED16.1 (VDD)

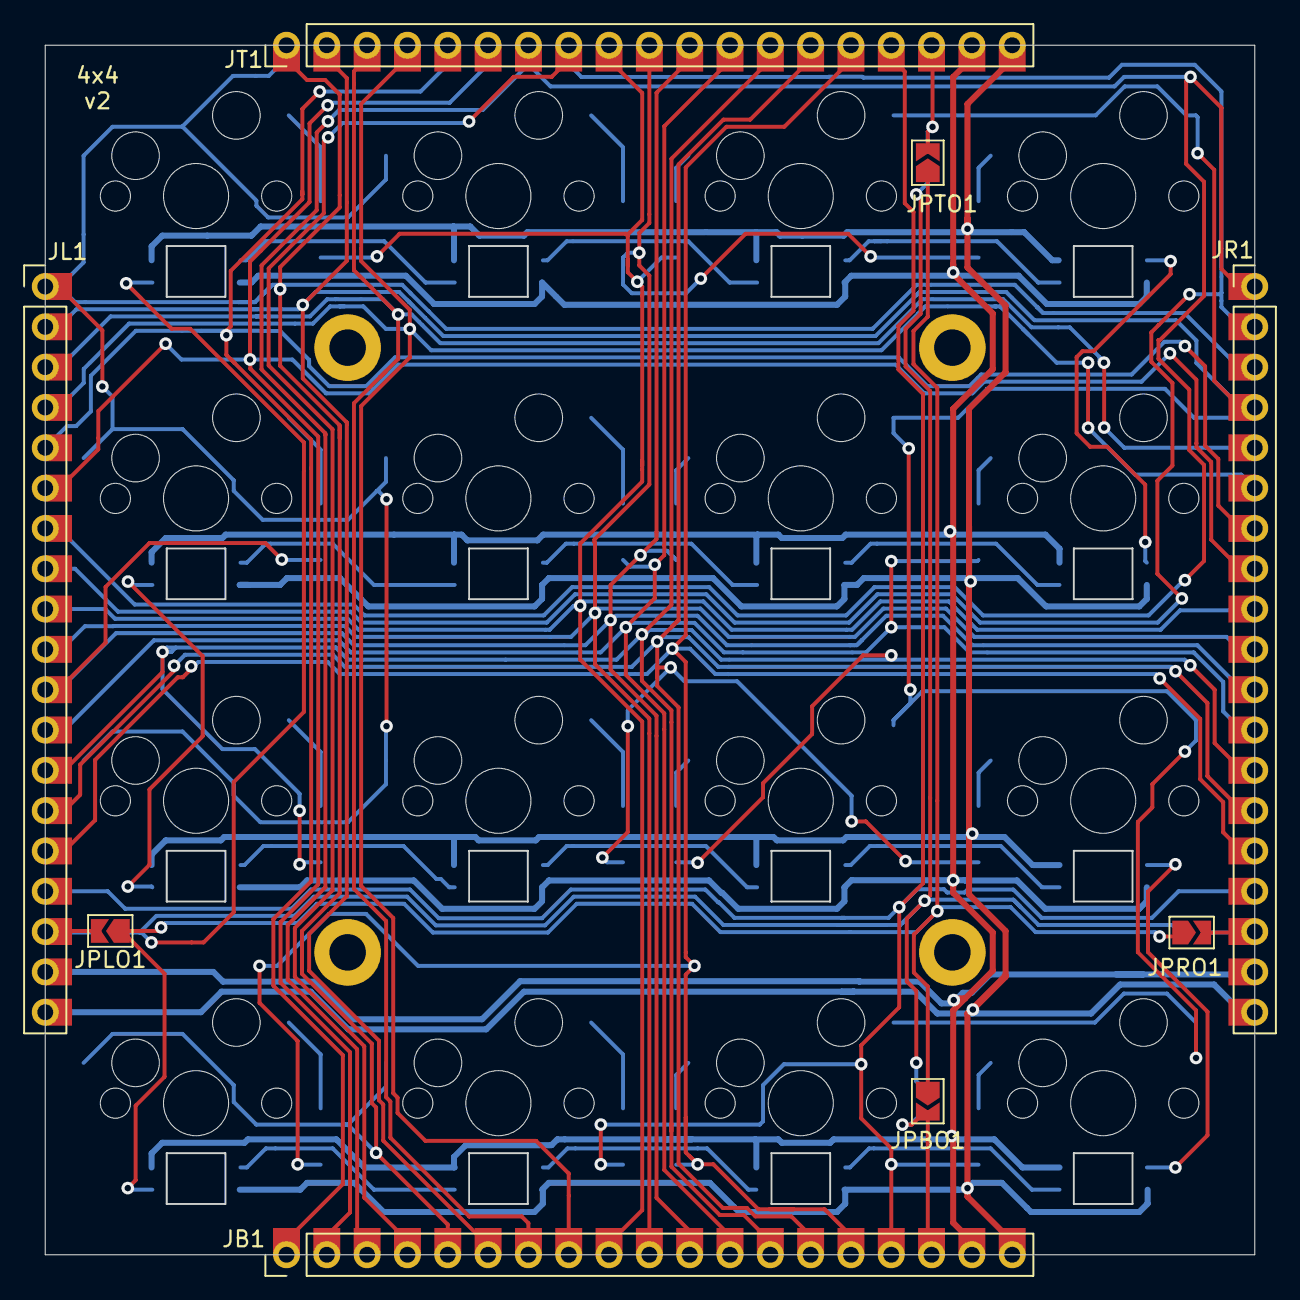
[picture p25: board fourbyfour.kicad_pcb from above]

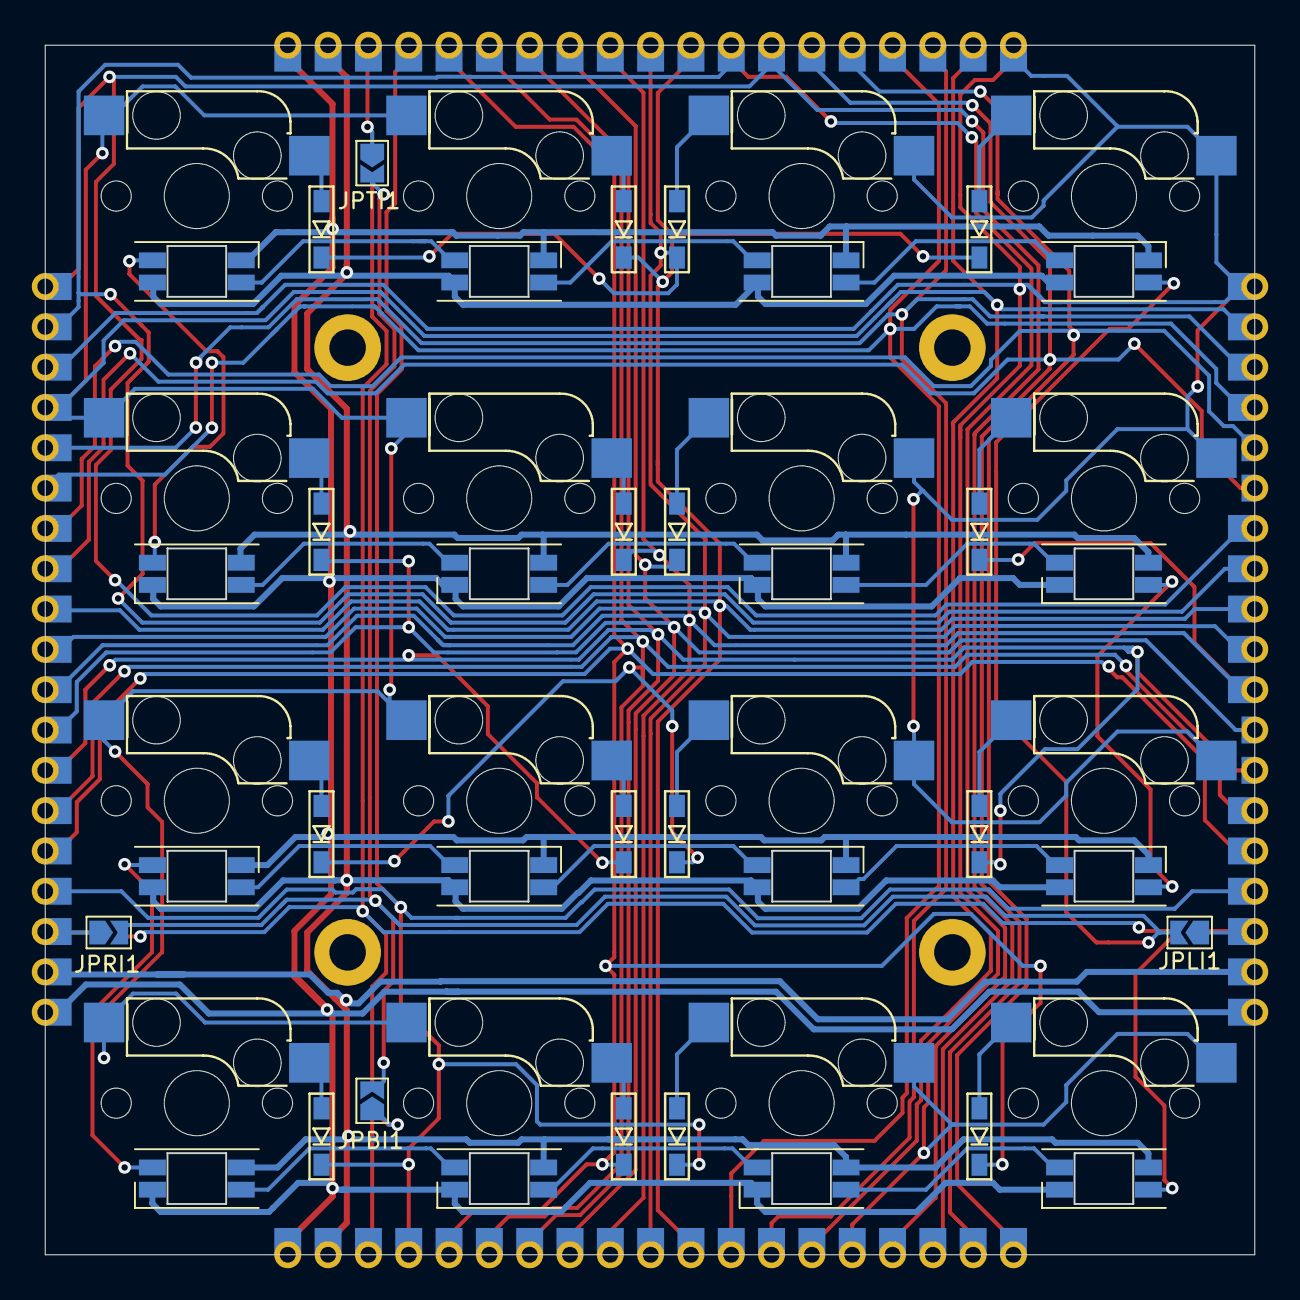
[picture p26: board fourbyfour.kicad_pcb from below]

Board: 2 copper layers, 76.2 x 76.2 mm, 60 parts (36 on the bottom side), 55 nets.

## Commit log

2022-11-12 Add 3d printed files
    [4x4holder.stl, planck_case_half.stl, planck_case_left.stl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]
2022-11-12 Add key module PCB
    [fourbyfour.kicad_pcb, fourbyfour.sch]
2022-11-12 Update gerber path
    [fourbyfour.kicad_pcb]
2022-11-12 Add the head PCB
    [headfour.kicad_pcb, headfour.sch]
2022-11-13 Add references to gerbers
